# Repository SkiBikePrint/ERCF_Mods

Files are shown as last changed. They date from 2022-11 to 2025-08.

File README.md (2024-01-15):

# ERCF_Mods
These files are for a 2020 extrusion based ERCF top mounting that integrates into a set of handles for a Voron Trident or V2.  It includes a roller based spool feed system as well as a 3 and 4 slot 1000mm buffer design.
#
#





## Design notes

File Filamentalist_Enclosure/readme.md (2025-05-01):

# <h1 align="center"> The Filamentalist Enclosure repo can now be found as part of the ERCF V2 project as a User Mod [here](https://github.com/Enraged-Rabbit-Community/ERCF_v2/tree/master/Recommended_Options/Filamentalist_Rewinder/Filamentalist_Enclosure) <p align="center"> #

The Filamentalist Enclosure is a passive dry box designed to house the Filamentalist passive rewinder.  It  consists of (4) printed endcaps, (6) pieces of 2020 extrusion cut/ordered to the desired length, and 0.060" (1/16') polycarbonate sheet(s) cut to size. 

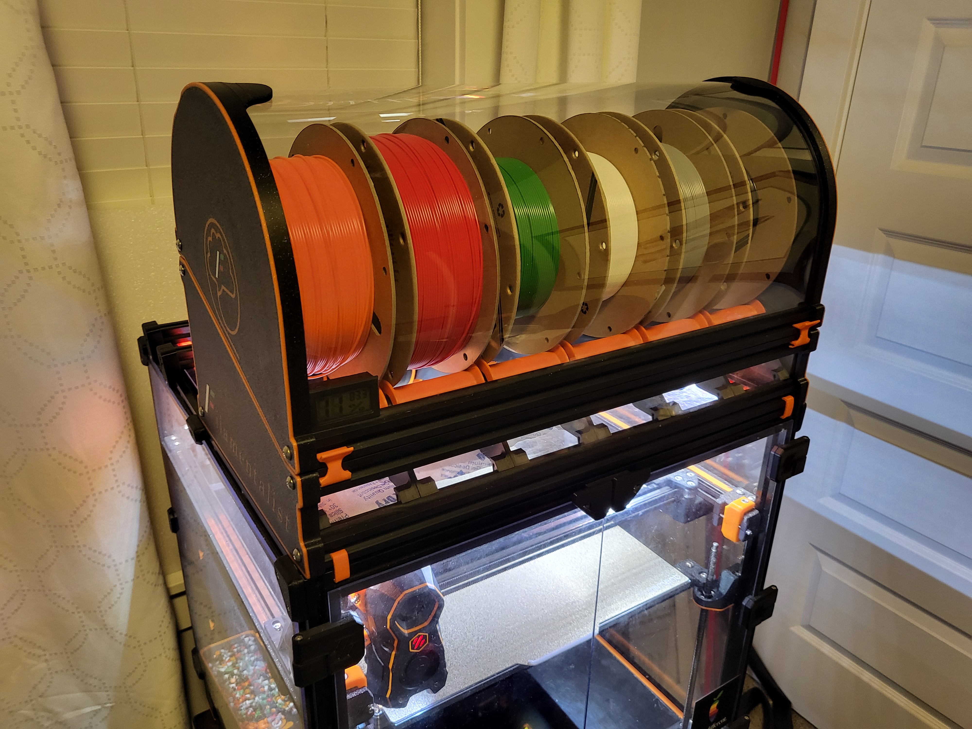
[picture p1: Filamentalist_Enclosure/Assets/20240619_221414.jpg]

</p>


</p>


</p>

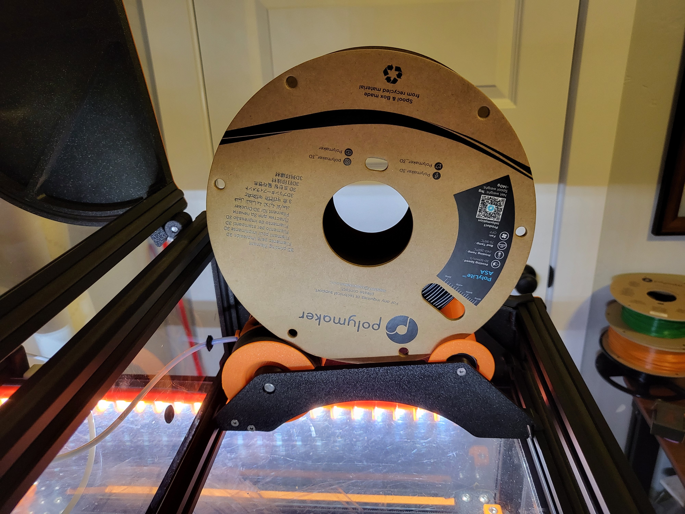
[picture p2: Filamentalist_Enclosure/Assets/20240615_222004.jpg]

</p>

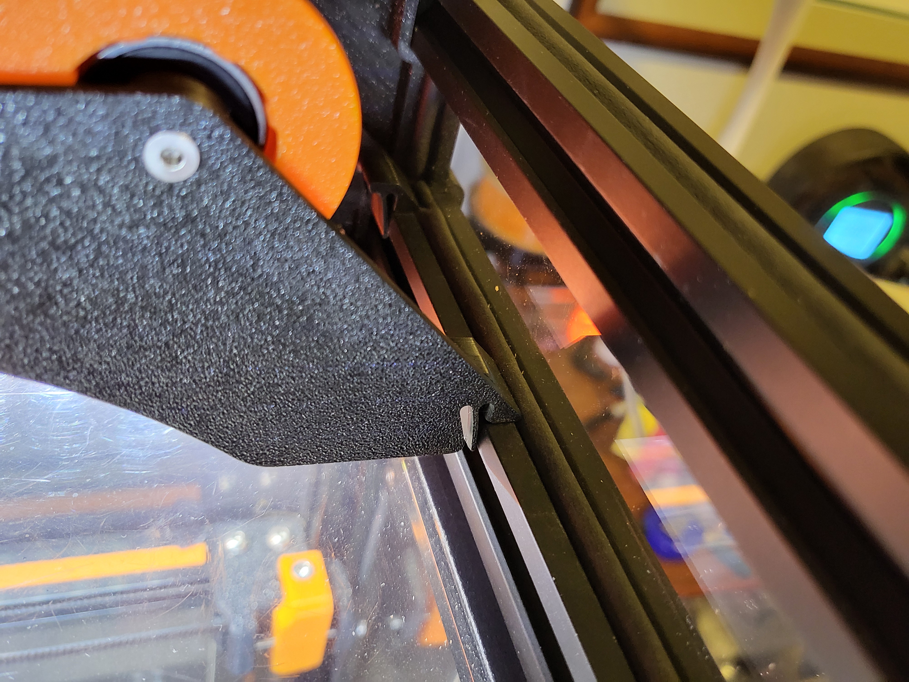
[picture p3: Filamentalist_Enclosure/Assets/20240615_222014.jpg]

</p>

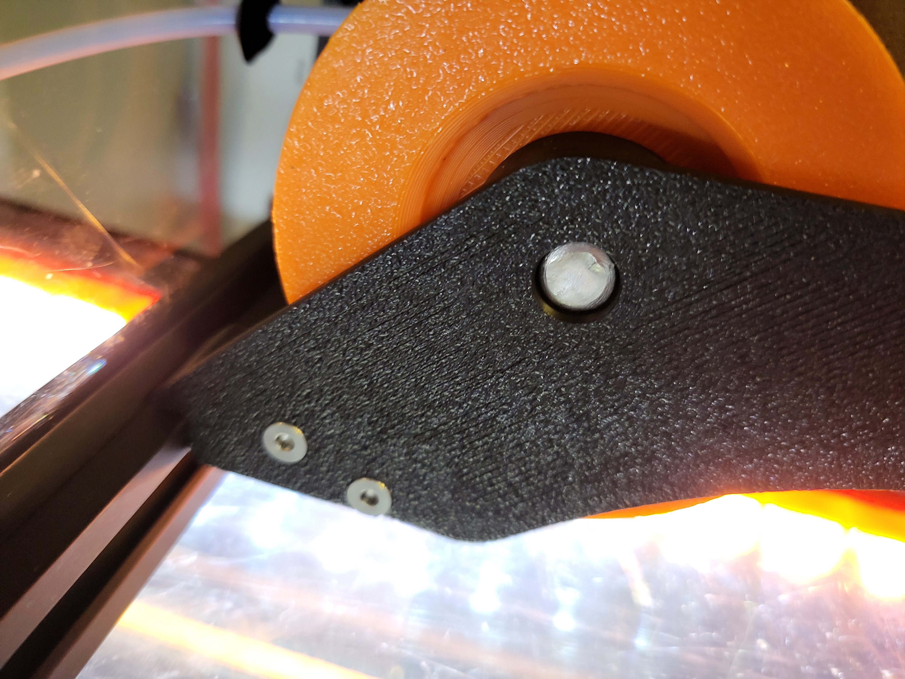
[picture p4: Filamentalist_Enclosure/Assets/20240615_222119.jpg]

</p>

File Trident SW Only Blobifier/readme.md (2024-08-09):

This allows for purging with blobs and using the hot end silicone jacket to knock the blobs off into a bin.  This is a solution for using Blobifier on a Trident.

I am loading/unloading my ERCF at 400/500 speed/accel (so pretty fast).  To be successful with that I want a pretty straight bowden run and this is why I chose to locate my Filametrix and purge site up front.  You can print multi-color up to ~35mm high under the gantry/toolhead, parts taller than this sacrifices the first ~100mm of build area at the font of the plate.  If you place yours in the rear you don't give up build space.  You will be limited to a max height of around 150mm. Taller than this and the part will hit the top of the enclosure when the plate returns to Z0 for blob formation.

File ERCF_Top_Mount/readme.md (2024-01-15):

This is a This is 2020 extrusion based top mount for the ERCF (Enraged Rabbit Carrot Feeder Multi-material unit developed by ette and the Voron community) 
on Voron 2.x and Trident printers.  The solution includes standalone end mounts adapted from NikosSprocket 
(https://www.printables.com/model/301808-ercf-frame-legs-for-voron-24-300mm) and 2020 mounts integrated into the "Sturdy Handle" adapted from synthden. 

Assembly tip:  The handles are designed to roll into the 2020 extrusion slots.  Because of this roll-in design, following the installation of the first 
handle the extrusions must be inserted to the full depth of the extrusion pockets to create enough space to roll in the opposing handle.  Once the second 
handle is installed, the extrusions can be partially slid back out from the first handle pockets and into the second handle pockets.  Now the extrusions are 
fully captured and can not come out without the removal of one (or both) handles.



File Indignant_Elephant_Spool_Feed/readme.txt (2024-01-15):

Indignant Elephant 2020 extrusion based simple spool roller

BOM

608-2RS Bearing qty (1)
M3x12 SHCS Screw (2)

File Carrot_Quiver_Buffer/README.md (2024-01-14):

# ERCF_Mods
The "Carrot Quiver" ( https://discord.com/channels/460117602945990666/909743915475816458/1040665326410530836 ) , and integrated multi-slot filament buffer to mount on the back of a 3D printer with a v-slot extrusion based frame or use with an intermediate frame system.

It allows a single 'loop' of filament to be buffered in the +/-1000mm range depending on printer frame height.  This system is intended to minimize filament path  drag compared to multi-loop wheel buffers and provide a quick and easy process for changing out filament spools.

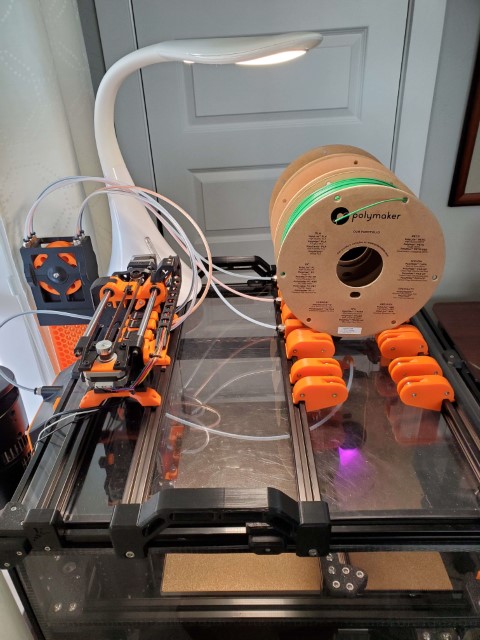
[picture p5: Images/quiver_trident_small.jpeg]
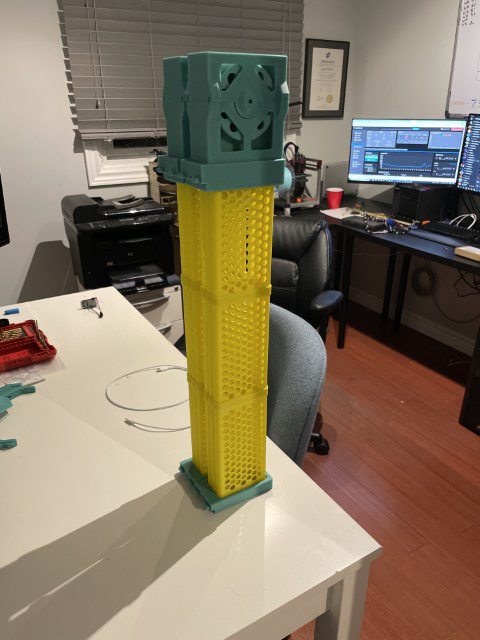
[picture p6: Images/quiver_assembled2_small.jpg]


## **BOM per 3 or 4 Slot Buffer:**

| **3/4 Slot Qty** | **Part** |
|---|---|
| 2/2 | 608-2RS bearing |
| 2/2 | M3x8 Socket Head Cap Screws (SHCS) to secure wheel axle (x12 or x16 length is fine too) |
| 6/8 | ECAS press-in pneumatic fittings for the bowden tubes (like used in ERCF) |
| 2/2 | M5 roll-in t-nuts for Top and Bottom frame mounts |
| 2/2 | M5x16 Socket Head Cap Screws for Top and Bottom frame mounts |
| 12/12 | 6x3mm neodymium magnets |

## **Printing Guidelines:**

## **General:**
- Material: ABS (~450 gm for 3 slot buffer and 600gm for 4 slot buffer)
- 0.2mm layer height
- 40% infill recommended (20% would be fine if you were in a hurry).  Linear style infills are fastest (rectilinear, monotonic, grid, triangles, stars, etc.)
- Wall Count: 4
- Solid Top/Bottom Layers: 5

## **Part Specific:**
- Orientation suggestions are relative to the installed part orientation in a vertically mounted quiver

## **Common for Trident and V2 all Z heights**

| **Qty** | **Part (3/4 3-slot/4-slot versions)** | **Orientation** | **Printed Supports Needed** |
|---|---|---|---|
| 1 | Axle | Vertical | N |
| 1 | Axle Spacer | Vertical | N |
| 1 | Bottom Block | Upside down | Y - under mounting overhangs |
| 1 | Filament Slots(3/4) Lower | Vertical | Y - under slot dividers at base |
| 1 | Top Mount | Vertical | Y - under slot dividers at base |
| 1 | Wheel | Horizontal | N |
| | -Slower printing 4-slot Spoke and Sexy Turbine options included | | |
| 1 | Wheel Block | Upside Down | N |

Wheel.stl, Axle.stl, Axle Spacer.stl

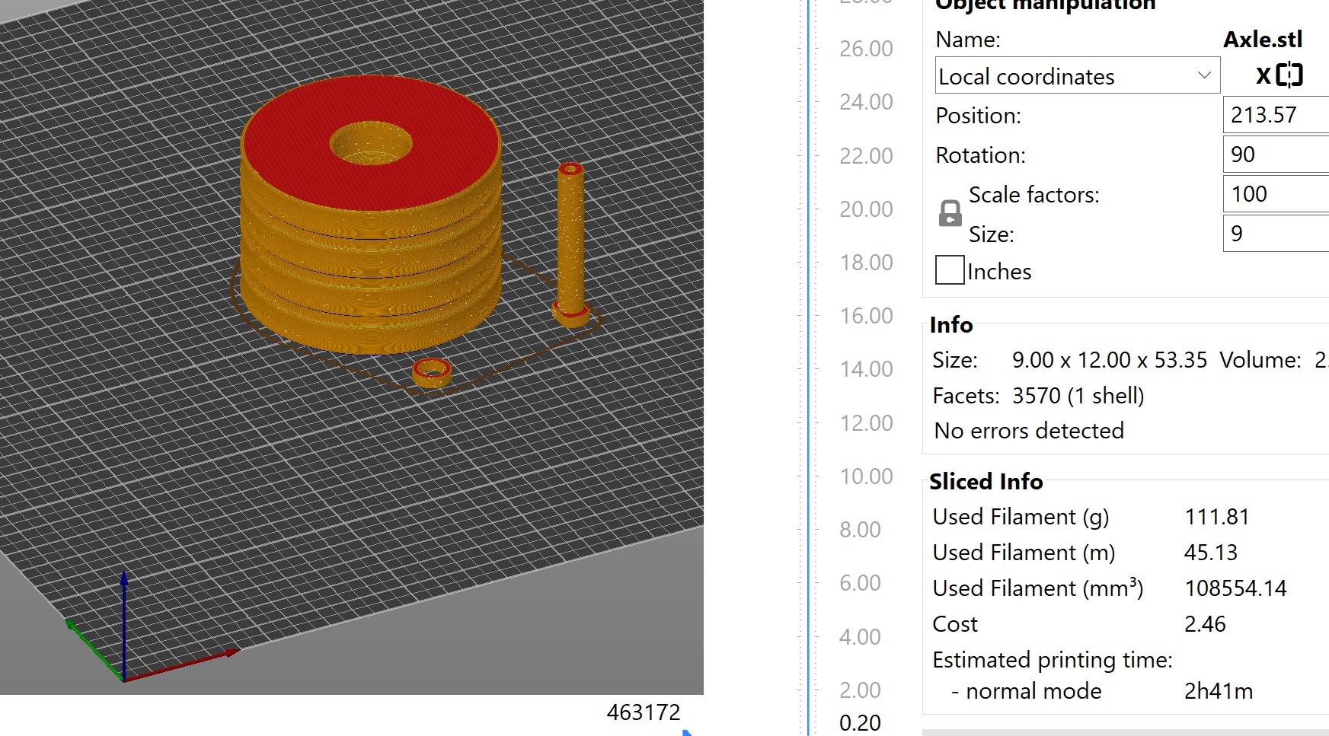
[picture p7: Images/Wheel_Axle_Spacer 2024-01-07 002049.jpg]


Bottom Block.stl



Filament Slots(3/4) Lower.stl



Top Mount.stl



Wheel Block.stl



>### Voron V2 Specific

| **Qty** | **Part** | Orientation |  **Printed Supports Needed** |
|---|---|---|---|
| 2 | Filament Slots(3/4) V2-(350/300/250) x2  | Vertical | Y - under slot dividers at base |

>### Voron Trident Specific (250mm Z travel)

| **Qty** | **Part** | Orientation |  **Printed Supports Needed** |
|---|---|---|---|
| 2 | Filament Slots(3/4) Trident x2 | Vertical | Y - under slot dividers at base |

Filament Slots(3/4) [...].stl



Assembly Steps:
1. Press fit the (2) MR608-2RS bearings into each side of the wheel. It is IMPORTANT to press to the full depth of the pocket in the wheel.  You can use a second wheel bearing as a pressing tool to drive the bearing in to full depth.
2. Press Axle through bearing flush to the shoulder on the axle.  
3. Press a total of (12) 6x3mm neodymium into the Wheel Block and Top Mount.  Take care to get orientation the same for all 6 on each part correct so that they attract to each other and allow for the Wheel Block to be oriented on the Top Mount in either direction as it is a symmetrical part.  Removal slots are designed in for the magnets if you need to pop any out.  These should be a strong press fit bit depending on your print toleraces you can add a dab of superglue in the bottom of each hole as you are installing (again, confirm orientation before commiting to glue!).  Also, note that the magnets that are located on the ends of the Wheel Block and Top Mount serve as alignment features.  The two on the top mount should slightly protrude above the surface (~1mm) and be recessed in the Wheel Block.  If further positive alignment is needed (but there shouldn't be a need) there is also holes in the these two parts for (2) M3 socket head cap screws.  You can screw the cap screws into the undersized holes in the Wheel Block.  The Top Mount has holes to receive the larger diameter of the socket head of the screws as a slip fit.
4. Press Axle Spacer onto axle flush to bearing.
5. Slide wheel and axle into Whell Block.  The is a keying feature in the wheel block to align to the flat edges on the shoulder feature of the axle.  This prevents the axle from spinning when installing/deinstalling the M3 axle screws.
6. Screw in M3x16 into holes in axles. You will be cutting threads in the axle plastic so do not over tighten.
7. This design is intentionally tight toleranced so that filament can not cross paths in the wheel tracks.  If there is any rubbing/interference with the wheel and Wheel Block or Top Mount, locate offending spot(s) and clean up with exacto, sandpaper, etc.
8. Mount top and bottom mounts onto printer extrusions in the desired location using M5 roll-in T-nuts and M5x16 socket head cap screws.  Once buffer is fully assembled it is necessary to remove the slots to access these screws so you will want to get the mounts positioned into their final location if possible.  It is not the end of the world if you have to move them, it just takes a few minutes to pop the slots back out of the mounts.
9. Slide the first section of the "Filament Slots 165" part into top mount.  It will not snap into place so you need to hold it in place for now (or temporaily tape it up).
10. Slide the second "Filament Slots 165" part into the slots above it.
11. Slide the third section, the "Filament Slots Lower 165" part (it has a floor) into the bottom mount from below.  Firmly press it upwards until it snaps into place.  If you need to remove this part to remove or relocate the buffer you can use a flat bladed screwdriver to gently pry each side of the buffer slots from below while pushing down on the buffer slots to clear the retention tabs.

Congratulations, you are ready load some carrots into your quiver!  Does that sound inappropriate...???

I will caution that this design has tight tolerances around the wheel so that filament can not get lodged in any gaps or neighboring slots.  This means the axle needs to be aligned well and any rubbing between the wheel and the upper quiver parts may need to be filed, sanded, exacto knifed away.  I use 3 mm and 4mm drill bits to clean up the bowden tube holes.  ~41mm of 4mm bowden tubing should insert through the fitting and down to where it seats in the Wheel Block.  If it does not go in ~41mm then the hole needs to be cleaned out with a 4mm drill bit.  Do not clean out the hole any deeper than 41mm as there is a step down to 3.2mm at this point to serve as a stop for the tubing.  You can run a 3mm drill bit through the entire hole if necessary to ensure an open path for filament.  So this design does require a little bit of post processing and tuning but once right it works well and is easy to thread and gain access to the filament.  All these little measures result in a surprisingly easy buffer to load.

Happy multi-color printing!
#





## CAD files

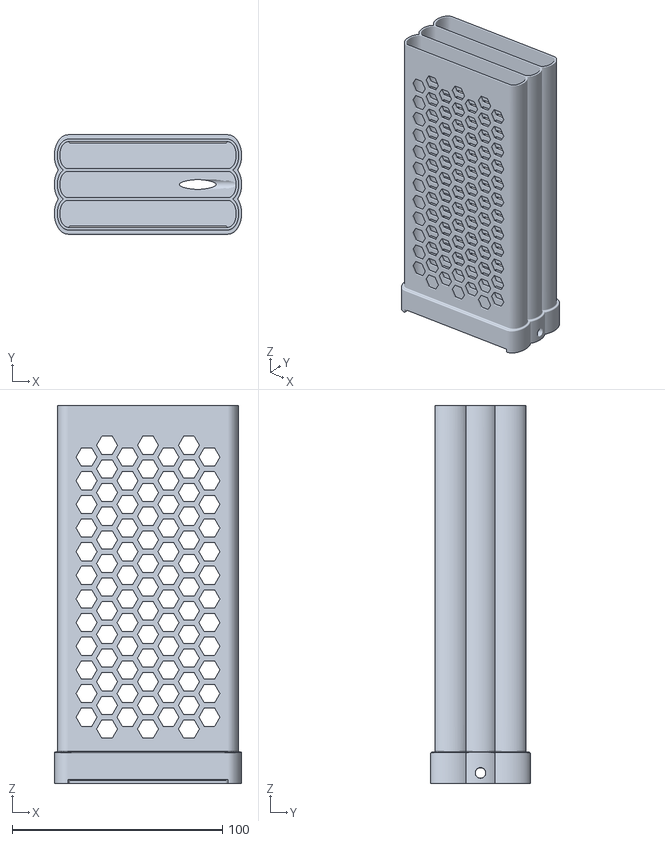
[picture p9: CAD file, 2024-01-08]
Carrot_Quiver_Buffer/3 Slot/Filament Slots(3) Lower.stl
89.2 x 47.4 x 180.0

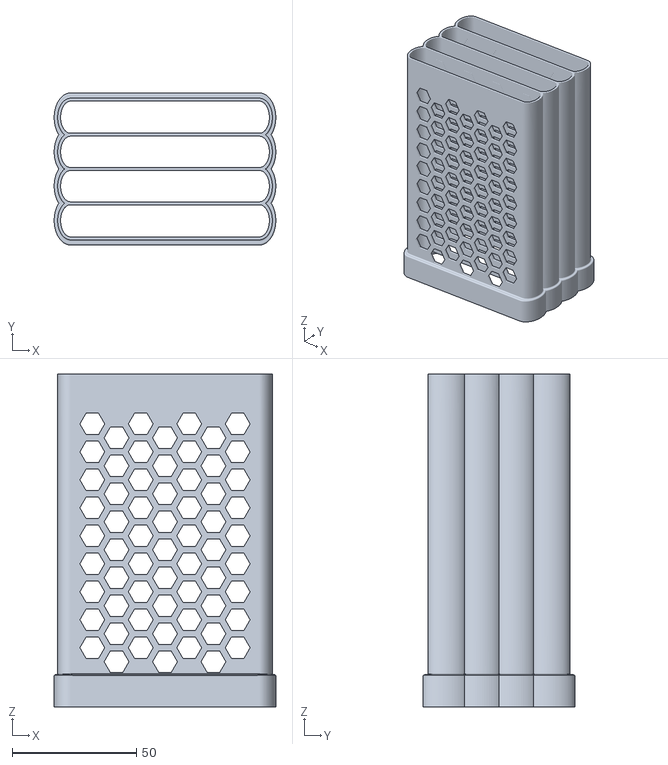
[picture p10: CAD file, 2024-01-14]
Carrot_Quiver_Buffer/4 SLot/Filament Slots(4) V2-250 x2.stl
89.2 x 61.2 x 134.0

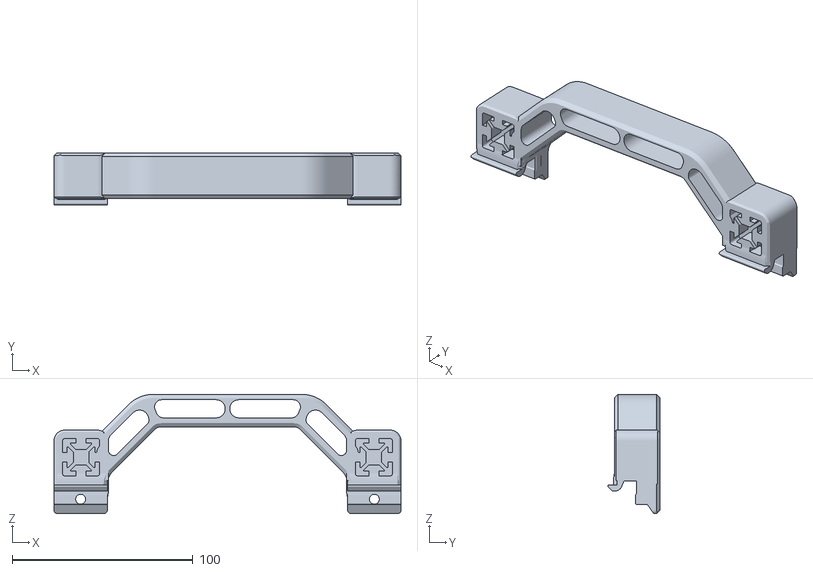
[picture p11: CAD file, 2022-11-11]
ERCF_Top_Mount/ERCF Sturdy Handle Frame Mount v3.stl
191.8 x 28.9 x 66.0

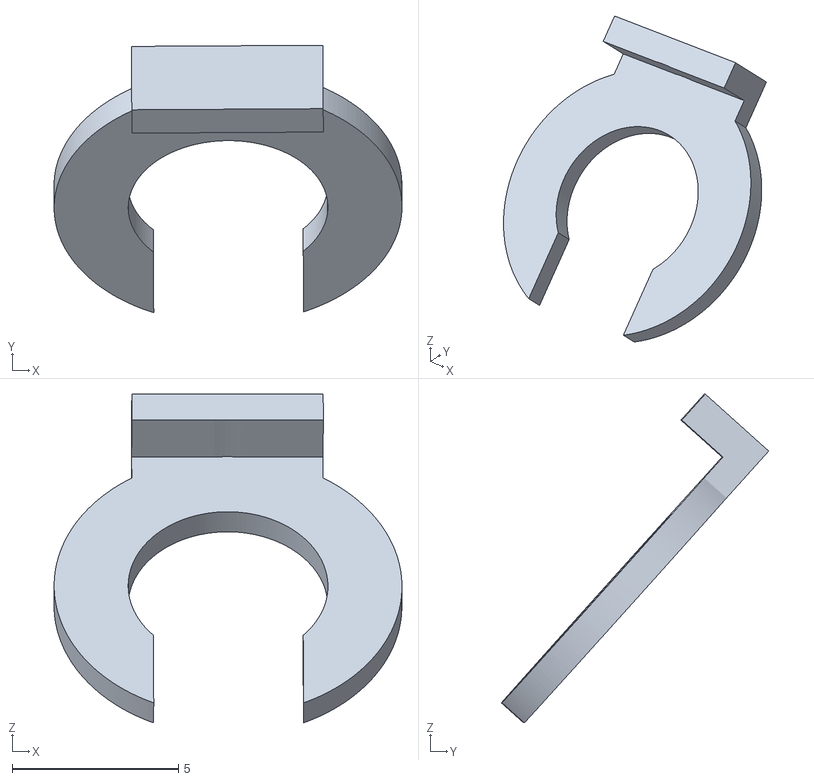
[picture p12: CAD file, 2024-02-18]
Filamentalist/STL's/ECAS Clip v21.stl
10.5 x 8.03 x 9.88

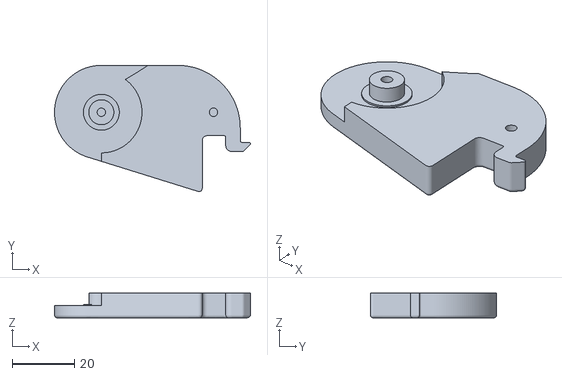
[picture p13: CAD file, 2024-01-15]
Indignant_Elephant_Spool_Feed/Bearing Clip Right.stl
62.7 x 40.4 x 8.00

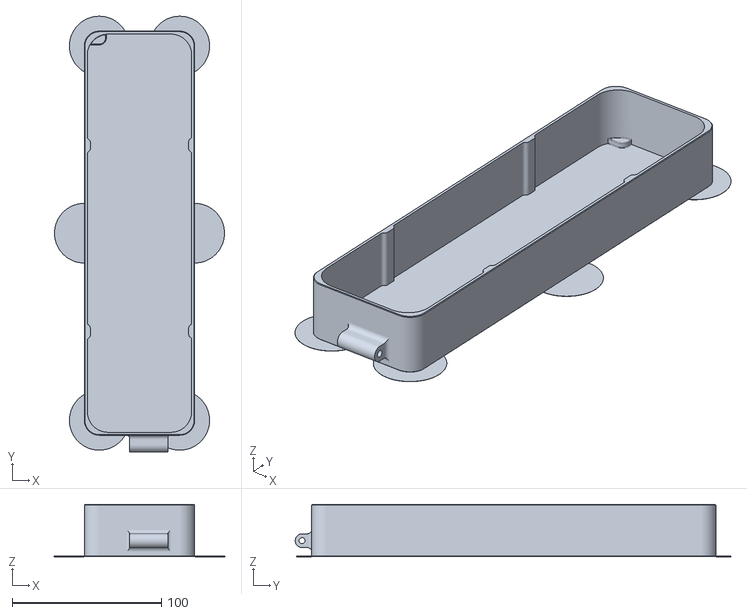
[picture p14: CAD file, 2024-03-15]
Trident SW Only Blobifier/stls/Blob Bucket 250.stl
114.0 x 292.1 x 35.0

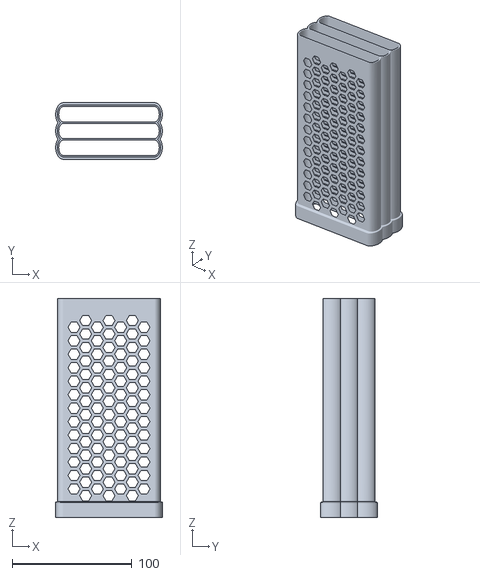
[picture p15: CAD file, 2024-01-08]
Carrot_Quiver_Buffer/3 Slot/Filament Slots(3) V2-350 x2.stl
89.2 x 47.4 x 183.0

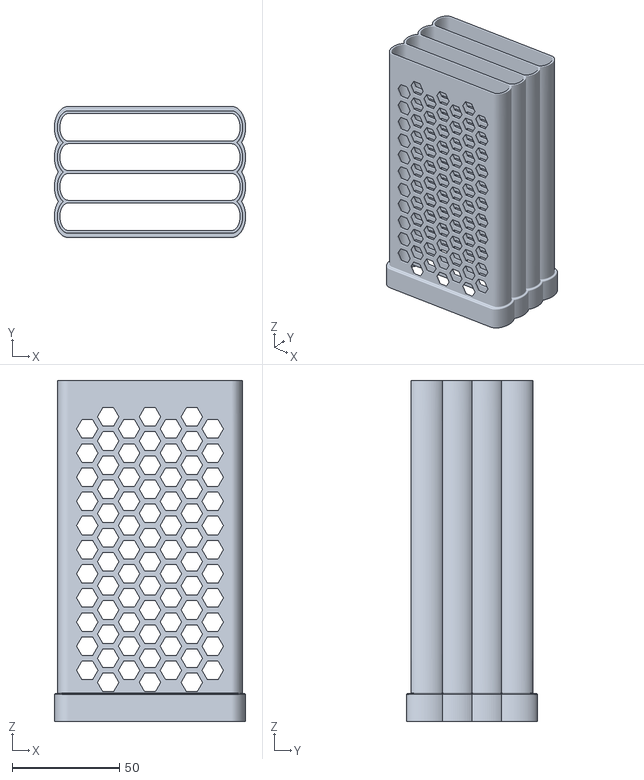
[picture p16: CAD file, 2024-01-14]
Carrot_Quiver_Buffer/4 SLot/Filament Slots(4) V2-300 x2.stl
89.2 x 61.2 x 159.0

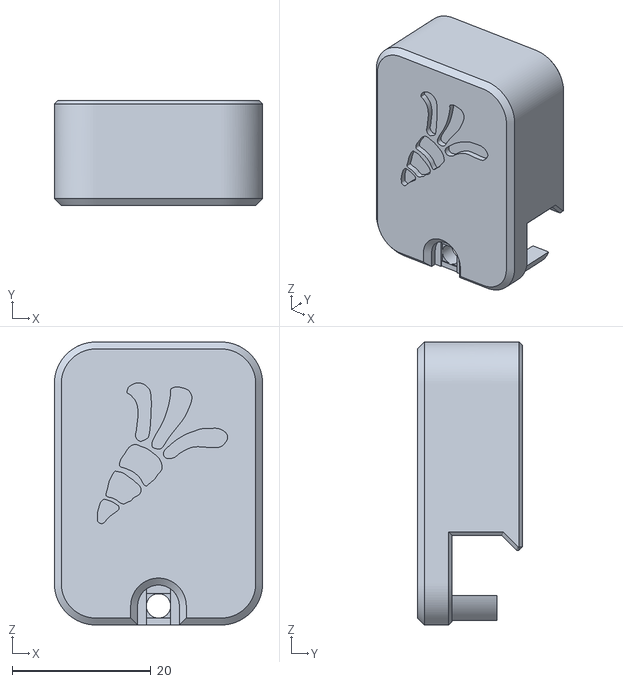
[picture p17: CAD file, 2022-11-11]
ERCF_Top_Mount/ERCF Frame Mount v3.stl
30.0 x 15.1 x 40.8

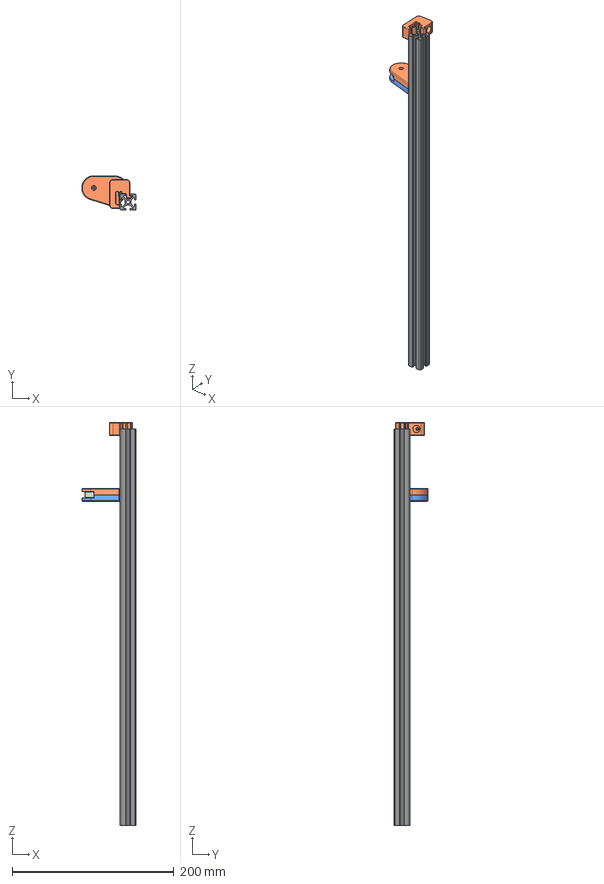
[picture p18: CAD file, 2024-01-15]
Indignant_Elephant_Spool_Feed/2020 Mounted Spool Rollers v1.step
67.3 x 42.5 x 498.0 mm
5537T751_T-Slotted Framing
Bearing Clip Left
Bearing Clip Right
Bowden Mount
2349K744_Permanently Lubricated Ball Bearing (5) (2) (1)

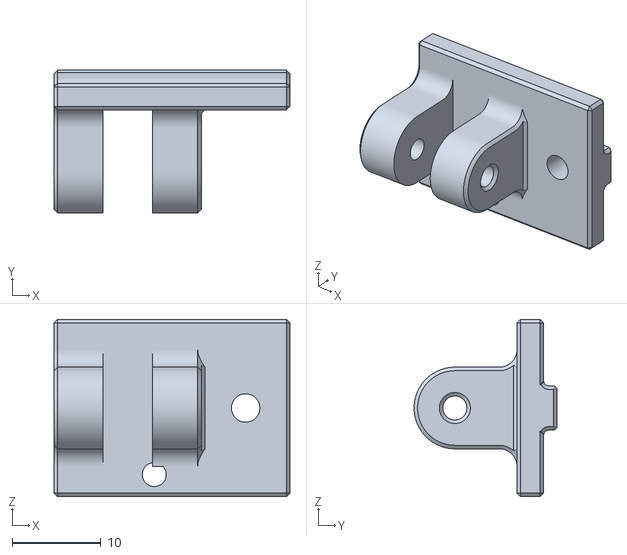
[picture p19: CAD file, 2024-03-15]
Trident SW Only Blobifier/stls/Arm Mount.stl
26.6 x 16.1 x 20.0

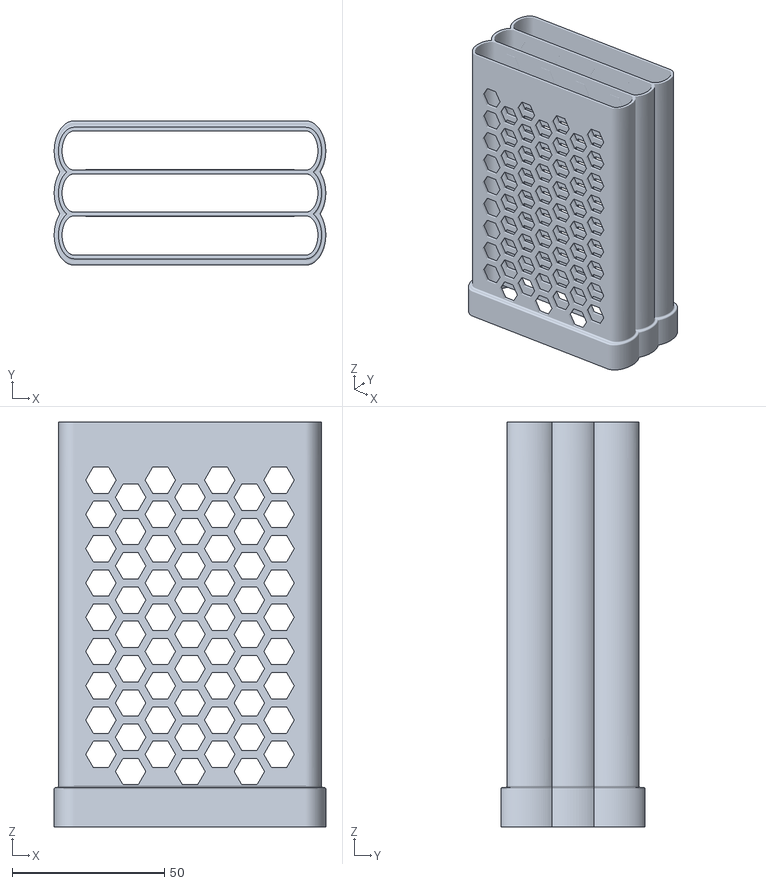
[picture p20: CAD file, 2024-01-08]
Carrot_Quiver_Buffer/3 Slot/Filament Slots(3) V2-250 x2.stl
89.2 x 47.4 x 133.0

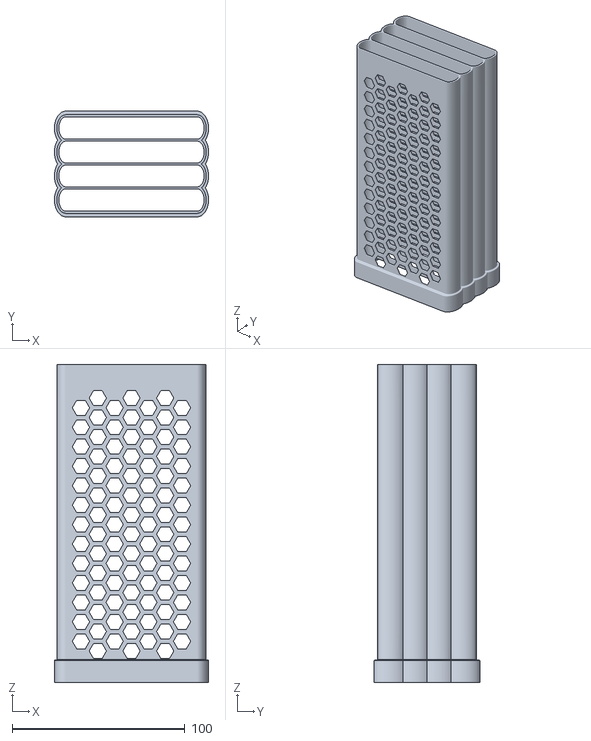
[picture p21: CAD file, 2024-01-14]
Carrot_Quiver_Buffer/4 SLot/Filament Slots(4) V2-350 x2.stl
89.2 x 61.2 x 184.0

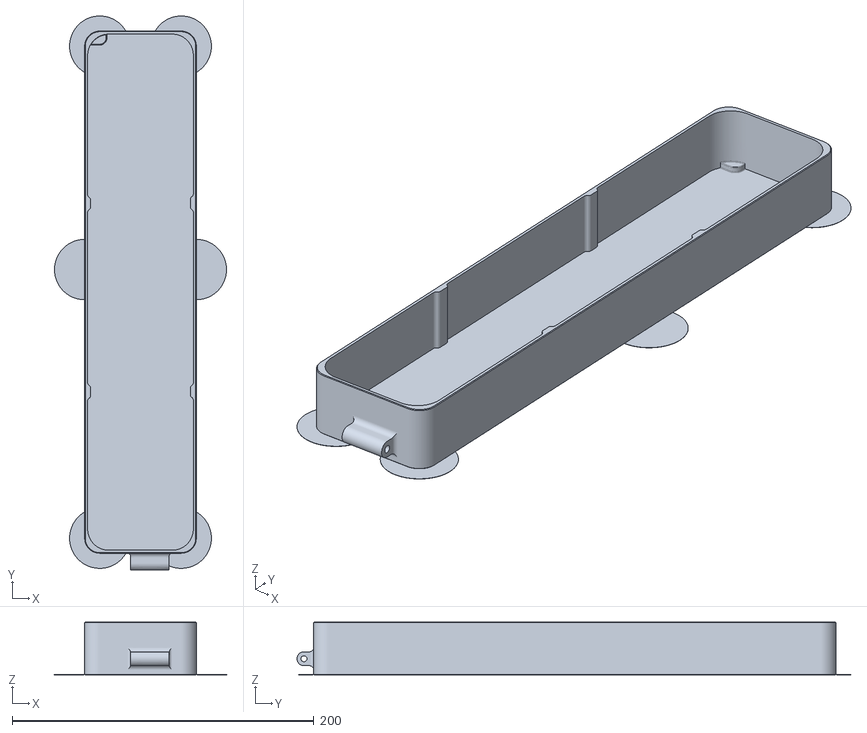
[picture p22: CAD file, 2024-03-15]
Trident SW Only Blobifier/stls/Blob Bucket 350.stl
114.0 x 367.1 x 35.0

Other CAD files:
Indignant_Elephant_Spool_Feed/Bearing Clip Left.stl
Carrot_Quiver_Buffer/3 Slot/Filament Slots(3) V2-300 x2.stl
Carrot_Quiver_Buffer/4 SLot/Filament Slots(4) Lower.stl
Indignant_Elephant_Spool_Feed/Bowden Mount.stl
Carrot_Quiver_Buffer/3 Slot/Axle Spacer.stl
Carrot_Quiver_Buffer/3 Slot/Axle.stl
Carrot_Quiver_Buffer/3 Slot/Bottom Block.stl
Carrot_Quiver_Buffer/3 Slot/Filament Slots(3) Trident x2.stl
Carrot_Quiver_Buffer/3 Slot/Top Mount.stl
Carrot_Quiver_Buffer/3 Slot/Wheel Block.stl
Carrot_Quiver_Buffer/4 SLot/Axle.stl
Carrot_Quiver_Buffer/4 SLot/Bottom Block.stl
Carrot_Quiver_Buffer/4 SLot/Filament Slots(4) x2 Trident.stl
Carrot_Quiver_Buffer/4 SLot/Top Mount.stl
Carrot_Quiver_Buffer/4 SLot/Wheel Block.stl
Indignant_Elephant_Spool_Feed/2020 Mounted Spool Rollers v0.f3d
Trident SW Only Blobifier/stls/Arm Lower.stl
Trident SW Only Blobifier/stls/Arm Upper.stl
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

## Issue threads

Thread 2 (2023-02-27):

The wheel block geometry is badly broken

jwhite, 2023-02-27:
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

As you can see, there are numerous bad polygons and shifted faces on the inside of both models.

jwhite, 2023-03-18:
I fixed this in the pull request https://github.com/SkiBikePrint/ERCF_Mods/pull/4

SkiBikePrint, 2024-01-13:
I incorporated your cleaned up geometry.  Thanks!

Closed 2024-01-13.

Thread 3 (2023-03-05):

Need a way to get Top Handle Extrusion Mount onto the printer

pfielding, 2023-03-05:
The top handle extrusion mount looks great, but I don't see any way to actually mount it on the printer without taking apart the extrusion on the printer.  The handle needs to normally tilt inwards to be able to clip into the printer extrusion, but the top extrusion that it will be holding, prevents the handle from tilting.  Any suggestion on how to actually mount the thing would be awesome....

jwhite, 2023-03-18:
The quiver slots up from the bottom, through the bottom mount, and then up into the top mount.

You don't mount the top mount with the qwiver parts (the mesh) inside.

The instructions were good, but a bit hard to follow.

SkiBikePrint, 2024-01-15:
I created a readme with these instructions I had posted on Thingiverse when I originally created this design: "Assembly tip: The handles are designed to roll into the 2020 extrusion slots. Because of this roll-in design, following the installation of the first handle the extrusions must be inserted to the full depth of the extrusion pockets to create enough space to roll in the opposing handle. Once the second handle is installed the extrusions can be then be slid back out from the first handle pocket and into the second handle pockets. Now the extrusions are fully captured and can not come out without the removal of one (or both) handles."

Closed 2024-01-15.

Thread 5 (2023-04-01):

PC4-M10 ptfe ports.. and tolerances?

LAP87, 2023-04-01:
So i've printed and reprinted the M3 wheel block with the holes for the ptfe connectors, but each time they crack and/or bulge the plastic around the hole and end up crooked.
Could you please fix the hole geometries so they can print supportless  (like voron parts), and also add M10 threads + tolerances?

M3 bolt holes are way too small for easy heat set insert insertion.

Also, i don't think you mention anywhere the preferred orientation for printing any of the parts.

LAP87, 2023-04-01:
Or add an optional ECAS04 port version of the top, i have a bag full of those!

SkiBikePrint, 2024-01-13:
The design is now ECAS only.

Closed 2024-01-13.

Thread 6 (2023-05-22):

Missing hole in Top/Bottom Mount?

Surion79, 2023-05-22:
I am currently trying to attach the Quiver to my printer, but while the BOM states the 2x M5x16 SHCS for mounting the Quiver, I don't see a chance to mount the Top Mount with the M5x16. The Upper Quiver stls have a hole which are apparently used for accessing the screw, but on the Top Mount, the opposite hole to access the M5x16 screw is missing.

The manual is exactly missing that bit of info how to tighten/access the M5x16 screw of the Top Mount.
Is there a hole missing in Top Mount? You can't access any M5x16 screws when the Quiver is fully assembled, which is required to attach it to the printer on both ends.

SkiBikePrint, 2024-01-13:
The mounts are installed prior to installing the slots which provides access to the M5 screws.

Closed 2024-01-13.

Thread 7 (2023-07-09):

Indignant_Elephant_Spool_Feed should have "washers" built in for the bearings!

grmocg, 2023-07-09:
The 608s I have are loose in the elephant, and rub along the sides when rolling.
If a small "washer" was put into the model around the bearing spindle, that'd be prevented, and the rollers would always roll as smoothly as they could!

SkiBikePrint, 2024-01-15:
Stand-off "washers" have been added.

Closed 2024-01-15.

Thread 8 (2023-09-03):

M5 heat insert, please mention outside Diameter?

MaikelKelder, 2023-09-03:
I printed the M5 heat insert version, but the M5 heat inserts I have are WAY too small and too long for this hole.

Please specify diameter of the used M5 heat insert, since its far from default.

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

MaikelKelder, 2023-09-03:
The hole is 8.9mm and 7.15mm deep.
For the next one, I now need to find and order right inserts..

SkiBikePrint, 2024-01-13:
M5 version has been removed

Closed 2024-01-13.

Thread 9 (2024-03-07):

Gear stepper gearing, NEMA17, etc..

moggieuk, 2024-03-07:
"Potential for being on the edge of gear motor stall. We are close to the stall threshold so the risk is that there is enough variation in the user community's ERCF builds, motors, and buffer builds that stall arises as an issue. I definitely have occasionally experienced stall if something caused a small increase in resistance. I may need to go NEMA17 to provide the headroom but will test on NEMA14 first."

Using an issue to provide some thoughts on this.  We know that the gearing for the gear stepper on the ERCF design is WAY off the optimum speed/torque point.   Obviously a NEMA17 is one way to go but better gearing is going to help.  This is something we have been experimenting with in a reworked gearbox design for a future ERCF update...  JFYI

thisiscam, 2024-03-11:
I believe a few testers are using the 1:2 gear mod by grafton (who is also testing the rewinder), and that worked well.
https://www.printables.com/model/692720-ercf-40-tooth-gear-modifiction.

For tradrack stock gear motor, the torque and gear ratio is plenty!

SkiBikePrint, 2024-03-16:
I am running Grafton's 40 tooth mod on the V2 and a NEMA 17 rated at 55Ncm torque and 2.0A holding current.  I have the max current configured at 1.2A and only see stalling when you would want it :)

Closed 2024-03-16.

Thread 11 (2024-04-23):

How to utilize pre_gate sensor in ERCF v2 with Quiver buffer?

AlexTOOT, 2024-04-23:
Thanks for the great work, I really enjoy the quiver buffer, simple but elegant design.

I'm wondering how to use pre-gate sensors together with it, I'm currently having cotton tail and quiver installed at the same time, filament goes through quiver to ERCT pre-gate sensor, pretty nasty. Is there a mod you recommend or a plan to introduce pre-gate sensors into quiver?

AlexTOOT, 2024-05-02:
To whom this might concern.
I found this triple-decky C9 version.
https://github.com/gneu42/Triple-Decky/tree/main

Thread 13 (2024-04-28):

Wrong O-ring size called up

1scottlyl, 2024-04-28:
The BOM states a 110 O-ring, where the amazon link is to a 211 O-ring. A 110 O-ring will not fit around the center roller.

Closed 2024-04-28.

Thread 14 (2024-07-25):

Filamentalist_Enclosure for Voron 2.4

salbang, 2024-07-25:
What would be the good extrusion length for voron 2.4 to have a nice fit on top of the printer?

Could you please explain some relative size like
voron 2.4 width +/- xxmm?

Thank you.

salbang, 2024-08-01:
Based on my measurement on the right and left endcap lid thickness, which is 10mm each, it seems that the right size for the extrusion length is voron 2.4 width - 20mm.

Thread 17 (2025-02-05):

Broken link to ERCF

bsafh, 2025-02-05:
This link https://github.com/Enraged-Rabbit-Community/ERCF_v2/tree/master/Recommended_Options/Filamentalist_Rewinder/User_Mods/SkiBikeMake/Filamentalist_Enclosure is broken,  so .. where are the STLs?

jusii, 2025-02-13:
Guess it's here https://github.com/Enraged-Rabbit-Community/ERCF_v2/tree/master/Recommended_Options/Filamentalist_Rewinder/User_Mods/Filamentalist_Enclosure

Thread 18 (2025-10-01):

Filamentalist Enclosure for Filamentalist V3

carl1961, 2025-10-01:
looked every where, the mounts in cad for Enclosure look like in picture. But I cannot figure out what I am missing here. what is the part that make this work together. is the enclosure actually for a older version? might have to make custom mounts to use this Enclosure?

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

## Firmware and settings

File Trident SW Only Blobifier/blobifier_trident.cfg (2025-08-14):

##########################################################################################
# Main macro. Usually you should only need to call this one or place it in the Happy Hare
# _MMU_POST_LOAD macro or variable_user_post_load_extension:
# PURGE_LENGTH=[float] (optional) The length to purge. If ommited it will check the 
#                      purge_volumes matrix or variable_purge_length
#PURGE_RET=[float]    (optional) The length to retract between moves
#
[gcode_macro BLOBIFIER_TRIDENT]
# These parameters define your filament purging. The retract variable is used to retract 
# right after purging to prevent unnecessary oozing. Some filament are particularly oozy 
# and may continue to ooze out of the nozzle for a second or two after retracting. Update 
# as necessary.
variable_purge_spd: 400	     # 8/10/24 - default 400, trying 200 (8 mm3/s) for TPU - Speed, in mm/min, of the purge.
variable_purge_temp_min: 255	     # Minimum nozzle purge temperature.
variable_retract_before_park: 0.0     # gpw - was 1 - amount in mm. 0 to disable
variable_retract_speed: 2000       # mm/m

# Adjust this so that your nozzle scrubs within the brush. Be careful not to go too low! 
# Start out with a high value (like, 6) and go 
# down from there.
#variable_brush_top: 6 

# These parameters define your scrubbing, travel speeds, safe z clearance and how many 
# times you want to wipe. Update as necessary.
variable_clearance_z: 2	         # When traveling, but not cleaning, the 
                                           #   clearance along the z-axis between nozzle 
                                           #   and brush.
#variable_wipe_qty: 2	         # Number of complete (A complete wipe: left, 
                                           #   right, left OR right, left, right) wipes.
variable_travel_spd_xy: 10000	         # Travel (not cleaning) speed along x and 
                                           #   y-axis in mm/min.
variable_travel_spd_z: 1000	         # Travel (not cleaning) speed along z axis 
                                           #   in mm/min.
variable_wipe_spd_xy: 10000	         # Nozzle wipe speed in mm/min.


# These parameters define the size of the brush. Update as necessary. A visual reference 
# is provided below.
# 
#                  ?   brush_width   ?                            
#                   _________________                                                          
#                  |                 |  ?                Y position is acquired from your 
#  brush_start (x) |                 | brush_depth       stepper_y position_max. Adjust 
#                  |_________________|  ?                your brush physically in Y so 
#                          (y)                           that the nozzle scrubs within the 
#                      brush_front                       brush.                                              
# __________________________________________________________
#                     PRINTER FRONT
# 
# 
# Start location of the brush. Defaults for 250, 300 and 350mm are provided below. 
# Uncomment as necessary
#variable_brush_start:          34	# For 250mm build    
#variable_brush_start:           67  # For 300mm build
variable_brush_start:          3  # gpw - revised for my setup - for 350mm build

# width of the brush
#variable_brush_width:          35	

# Location of where to purge. The tray is 15mm in length, so if you assemble it against 
# the side of the bed (default), 10mm is a good location
variable_purge_x: 3

# Height of the tray. If it's below your bed, give this a negative number equal to the 
# difference. If it's above your bed, give it a positive number. You can find this number 
# by homing, optional QGL or equivalent, and moving you toolhead above the tray, and 
# lowering it with the paper method. 
variable_tray_top: 0.0


# ========================================================================================
# ==================== BLOB TUNING =======================================================
# ========================================================================================

# The following section defines how the purging sequence is executed. This is where you 
# tune the purging to create pretty blobs. Refer to the visual reference for a better 
# understanding. The visual is populated with example values. Below are some guides 
# provided to help with tuning.
#
#                          \_____________/
#                             |___|___|
#                                \_/            ______________  < End of third iteration.
#                                / \                                  HEIGHT:   3 x iteration_z_raise - (2 + 1) x iteration_z_change  (3 x 5 - 2 x 1.2 = 11.4)
#                               |   |                                 EXTRUDED: 3 x max_iteration_length                              (3 x 50 = 150)
#                              /     \          ______________  < End of second iteration.
#                             |       \                               HEIGHT:   2 x iteration_z_raise - 1 x iteration_z_change        (2 x 5 - 1 x 1.2 = 8.8)
#                            /         |                              EXTRUDED: 2 x max_iteration_length                              (2 x 50 = 100)
#                           |           \       ______________  < End of first iteration. 
#                          /             \                            HEIGHT:   1 x iteration_z_raise                                 (1 x 5 = 5)
#                         |               |                           EXTRUDED: 1 x max_iteration_length                              (1 x 50 = 50)
#___________               \             /      ______________  < Start height of the nozzle. default value: 1.5mm
#           |_______________\___________/_      ______________  < Bottom of the tray
#           |_____________________________|
#           |
# 
########################### BLOB TUNING ##############################
# +-------------------------------------+----------------------------+
# |  Filament sticks to the nozzle at   | Incr. purge start          |
# |    initial purge (first few mm)     |                            |
# +-------------------------------------+----------------------------+
# |  Filament scoots out from under     | Incr. temperature          |
# |  the nozzle at the first iteration  | Decr. z_raise              |
# |                                     | Incr. purge_length_maximum |
# +-------------------------------------+----------------------------+
# |  Filament scoots out from under the | Decr. purge_spd            |
# |  the nozzle at later iterations     | Decr. z_raise_exp          |
# |                                     | Decr. z_raise              |
# |                                     | Incr. purge_length_maximum |
# +-------------------------------------+----------------------------+
# |  Filament sticks to the nozzle at   | Incr. z_raise_exp          |
# |         later iterations            |     (Not above 1)          |
# +-------------------------------------+----------------------------+
#

# The height to raise the nozzle above the tray before purging. This allows any built up 
# pressure to escape before the purge.
variable_purge_start: 0.2  # gpw - was 0.2


# The amount to raise Z
variable_z_raise: 15   # gpw - Should it be 19.5? 6.5[iteration_z] X 3[max_iterations_per_blob] from old version - 16.8 default (was this calculated from my previous version's settings?)

# As the nozzle gets higher and the blob wider, the Z raise needs to be reduced, this
# follows the following formula: 
#            (extruded_amount/max_purge_length)^z_raise_exp * z_raise
# 1 is linear, below 1 will cause z to raise less quickly over time, above 1 will make it
# raise quicker over time. 0.85 is a good starting point and you should not have it above 1
variable_z_raise_exp: 0.9  # gpw - 0.85 default

# Lift the nozzle slightly after creating the blob te release pressure on the tray.
variable_eject_hop: 0.0  

# Dwell time (ms) after purging and before cleaning to relieve pressure from the nozzle.
variable_pressure_release_time: 0  #gpw - was 1000

# Set the part cooling fan speed. Disabling can help prevent the nozzle from cooling down 
# and stimulate flow, Enabling it can prevent blobs from sticking together. Values range 
# from 0 .. 1, or -1 if you don't want it changed.
#variable_part_cooling_fan: -1              # Leave it unchanged
#variable_part_cooling_fan:  0              # Disable the fan
variable_part_cooling_fan:  1               # Run it at full speed


# ========================================================================================
# ==================== PURGE LENGTH TUNING ===============================================
# ========================================================================================
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

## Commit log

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2022-11-25 Add files via upload
    1. Updated the 8mm magnet press-in holes to eliminate break-out.
    2. Added an M3 wheel axle version for those how don't have M5 heat sets (choose "Wheel Block M3 Heat Set.stl" and "Axle M3.stl"
    [Axle M3.stl, Top Mount.stl, Wheel Block M3 Heat Set.stl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]
2022-11-25 Delete Wheel Block.stl
    Replaced with new version that prevents breakout when magnets are pressed in.
    [Wheel Block.stl]
2022-11-27 Modified to a 2 bearing wheel to improve lateral stability.
    [Axle M3 2 Bearing.stl, Axle M5 2 Bearing.stl, Axle Spacer 2 Bearing.stl]
2022-11-27 Delete Axle M3.stl
    Converting to a 2 Bearing design.
    [Axle M3.stl]
2022-11-27 Delete Axle Spacer.stl
    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
    [Axle Spacer.stl]
2022-11-27 Delete Axle.stl
    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
    [Axle.stl]
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2022-11-30 Add files via upload
    Revised Bearing Clip Right.stl to use the standard heatset inserts that use a 4.7mm diameter hole.
    [Bearing Clip Right.stl]
2022-12-22 Delete Wheel-2 Bearing.stl
    Adding in a new version with clearance around the axle.
2022-12-22 Add files via upload
    Revised wheel to have a 14mm center bore for clearance around axle.
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2024-01-08 Add files via upload
    Closed unnecessary "air bridge" in Filament Slots(3) Lower.stl for the center dividers. Exterior faces should be unconnected and supports used while printing. This provides the spring clip-in flexibility for snapping into the Bottom Mount.
    [Filament Slots(3) Lower.stl]
2024-01-08 Add files via upload
    Closed unnecessary "air bridge" in Filament Slots(4) Lower for the center dividers. Exterior walls should be unconnected at the base and supports used while printing. This provides the spring clip-in flexibility for snapping into the Bottom Mount.
    [Filament Slots(4) Lower.stl]
2024-01-13 Delete Carrot_Quiver_Buffer/Axle M3 2 Bearing.stl
    Removing old files based on the 1/7/24 update that added a 4-slot version and V2 support for 250/300/350 printers.
    [Axle M3 2 Bearing.stl]
2024-01-13 Delete Carrot_Quiver_Buffer/Axle M5 2 Bearing.stl
    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
    [Axle M5 2 Bearing.stl]
2024-01-13 Delete Carrot_Quiver_Buffer/Axle Spacer 2 Bearing.stl
    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
    [Axle Spacer 2 Bearing.stl]
2024-01-13 Delete Carrot_Quiver_Buffer/Bottom Block.stl
    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
    [Bottom Block.stl]
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2024-01-13 Delete Carrot_Quiver_Buffer/Filament Slots Lower.stl
    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
    [Filament Slots Lower.stl]
2024-01-13 Delete Carrot_Quiver_Buffer/Filament Slots Upper.stl
    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
    [Filament Slots Upper.stl]
2024-01-13 Delete Carrot_Quiver_Buffer/Top Mount.stl
    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
    [Top Mount.stl]
2024-01-13 Delete Carrot_Quiver_Buffer/Wheel Block M3 Heat Set.stl
    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
    [Wheel Block M3 Heat Set.stl]
2024-01-13 Delete Carrot_Quiver_Buffer/Wheel Block M5 Heat Set.stl
    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
    [Wheel Block M5 Heat Set.stl]
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2024-01-14 Add files via upload
    Added 1mm in height to V2 Filament Slots to eliminate the 2mm clearance on the original design. There was feed back that there was too much play in the slot-to-slot sleeving.
    [Filament Slots(4) V2-250 x2.stl, Filament Slots(4) V2-300 x2.stl, Filament Slots(4) V2-350 x2.stl]
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2024-01-15 Add files via upload
    Revised bearing clip for threading into plastic vs using heatset inserts. Added CAD files.
    [2020 Mounted Spool Rollers v0.f3d, 2020 Mounted Spool Rollers v1.step, Bearing Clip Left.stl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]
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2024-01-26 Delete Filamentalist/Filament Drive Buffer V4 v66.f3d
    Adding revised files to address Tensioner Mnt mounting error.
2024-01-26 Delete Filamentalist/Filament Drive Buffer V4 v66.step
    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
2024-01-26 Add files via upload
    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
2024-01-27 Add files via upload
    Add specific CAD directory and loaded updated CAD files that reflect the addition of one screw-on Rim Roller/Hub to provide access for O-Ring replacement.
2024-01-28 Add files via upload
    Slight tweaks:
    Recessed BHCS's on Tensioner arm 1mm and shortened to 16mm
    Lengthened tension screw to 45mm
    Reduced thread count on threaded rim roller to make assembly easier
    Reduced ECAS hole diameter by 0.1mm for more positive press fit
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2024-01-28 Add files via upload
    Updated for the 2020 Clip-In base option
    [Rear Roller Axle.stl]
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2024-01-29 Add files via upload
    Including STL's for CAD ver. 71
    [Axle Pressing Tool.stl, Center Drive Roller Spacer.stl, ECAS Clip.stl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]
2024-01-30 V71 Clip Mount Base Files
    Provide stl's for the 2020 Clip Mount version
    [Left Support Clip Mount.stl, Right Support Clip Mount.stl]
2024-01-30 Add files via upload
    A tiny tweak...Removed chamfers from spacer to provide more build plate adhesion surface are to eliminate the need for brims while printing.
    [Center Drive Roller Spacer.stl]
2024-02-01 V85
    Easy-load funnel Tensioner Mnt. Splined Rim Roller and Hub. Revised Axle Pressing tool for changes in Rim Roller.
    [Rim Roller Splined.stl, Tensioner Mnt.stl]
2024-02-01 V85
    Easy-load funnel version with better alignment to filament path.
    [Tensioner Mnt.stl]
2024-02-01 V85
    Corrected 608 bearing bosses to eliminate center race interference.
    [Left Support.stl, Right Support.stl]
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2024-02-01 Delete Filamentalist/CAD/Filament Driven Buffer v71.step
    replaced by v88
2024-02-01 v89
    Changes:
    1. Replaced threaded Rim Roller with splined version for ease of assembly and removal.
    2. Replaced c-sunk holes on Tensioner Arm with FH.
    3. Revised Tensioner mount for better ECAS alignment and "easy-load" filament funnel.
    4. Reversed the 608 bearing clearance bosses on the R/L Supports to allow the center race to spin freely.
    5. Thickened the wall of the rear roller to reduce stress marks from the pressed in 608 bearings.
    6. Removed the chamfers from the Center Drive Roller Spacers to improve build plate adhesion.
2024-02-01 v91
    Increased clearance around ECAS
    [Tensioner Mnt.stl]
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2024-02-01 v93
    1. Increased ECAS hole on Tensioner Mnt from 8.45mm D to 8.5.
    2. Added clearance for shaft on the end bearing bosses of the Rim Rollers to prevent mushrooming when pressing in shaft.
    3. Increased Rear Roller wall thickness to 2.8mm to reduce stress crazing for bearing press-in.
2024-02-01 v93
    revised clearance for the 608 bearing inner race
    [Left Support Clip Mount.stl, Right Support Clip Mount.stl]
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2024-02-18 v21 (rear wheel drive)
    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
    [Axle Pressing Tool v21.stl, Center Drive Roller Spacer v21.stl, Center Drive Roller v21.stl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]
2024-02-18 Delete Filamentalist/STL's/Left Support v21.stl
    Replaced with a light cosmetic tweak.
    [Left Support v21.stl]
2024-02-18 Delete Filamentalist/STL's/Right Support v21.stl
    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
    [Right Support v21.stl]
2024-02-18 Delete Filamentalist/STL's/Tensioner Mnt v21.stl
    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
    [Tensioner Mnt v21.stl]
2024-02-18 v21 (Rear Wheel Drive)
    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
    [Left Support v21.stl, Right Support v21.stl, Tensioner Mnt v21.stl]
2024-02-18 Delete Filamentalist/CAD/Filament Driven Buffer RWD v21.f3d
    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
    [Filament Driven Buffer RWD v21.f3d]
2024-02-18 Delete Filamentalist/CAD/Filament Driven Buffer RWD v21.step
    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
2024-02-18 v21 (Rear Wheel Drive)
    Updated with a light cosmetic tweak on Supports and Tensioner Mnt
    [Filament Driven Buffer RWD v21.f3d]
2024-02-18 Delete Filamentalist/STL's/Left Support v21.stl
    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
    [Left Support v21.stl]
2024-02-18 v21 (Rear Wheel Drive)
    Updated with a light cosmetic tweak.
    [Left Support v21.stl, Right Support v21.stl]
2024-02-18 v21 (Rear Wheel Drive)
    Updated for a slight cosmetic tweak.
    [Left Support (Clip Mount) v21.stl, Right Support (Clip Mount) v21.stl]
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2024-02-23 RWD v60
    Standardized on a single U-shaped Tensioner Arm. Slight quality of life adjustments to Tensioner Arms and Tensioner Mount (reprint not required for built buffers).
    [Filament Driven Buffer RWD v60.f3d]
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2024-02-26 RWD v60.1
    QoL improvements:
    1. Increased corner radii on triangular press-in peg of tensioner arm
    2. Moved screw position back on "nose" of tensioner are to provide more meat where screw head seats
    No need to replace already printed/built parts
    [Tensioner Arm Left.stl, Tensioner Arm Right.stl]
2024-02-26 Rename Tensioner Arm Left.stl to Tensioner Arm Left (RWD v60.1).stl
    [Tensioner Arm Left (RWD v60.1).stl]
2024-02-26 Delete Filamentalist/STL's/Tensioner Arm Left (RWD v60).stl
    Added small QoL tweaks in v60.1
    [Tensioner Arm Left (RWD v60).stl]
2024-02-26 Rename Tensioner Arm Right.stl to Tensioner Arm Right (RWD v60.1).stl
    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
    [Tensioner Arm Right (RWD v60.1).stl]
2024-02-26 Delete Filamentalist/STL's/Tensioner Arm Right (RWD v60).stl
    replaced with v60.1
    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
    [Tensioner Arm Right (RWD v60).stl]
2024-02-26 RWD V60.1
    These changes do not require reprinting of existing parts.
    Cleaned up artifact that was discovered in the .stp for the Left/Right Support components.
    Reduced contact area of triangular peg on Tensioner Arm Right
    Shifted FHCS hole back on Tensioner Arm Left at "nose" of part to reduce plastic break-out when tightening screw.
    [Filament Driven Buffer RWD v60.1.f3d, Filament Driven Buffer RWD v60.f3d]
2024-02-26 RWD v60.1
    Cleaned up artifact that was discovered in the STEP file for the Left/Right Support components.
    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
    [Left Support (RWD v60).stl, Left Support(RWD v60.1).stl, Right Support (RWD v60).stl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]
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2024-02-29 v6
    added clearance to 1mm spacers
    added chamfers to mag drive disc for printability
2024-03-08 Production Release! v1
    stl, f3d, and stp files released for the formal"production" version of the Filamentalist filament driven buffer
    [Axle Pressing Tool (RWD v60).stl, Axle Pressing Tool v1.stl, Center Drive Roller (RWD v60).stl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]
2024-03-10 Production Release v1!
    Added a standalone flat base for those who want it.
    [Base v1.stl, Base.stl]
2024-03-12 Add files via upload
    This is a Blobifier macro that allows a sw only Blobifier multimaterial purge method.
    [SW Only Blobifier.cfg]
2024-03-15 Add files via upload
    Including blob collection trays and articulated arm for tilting collection tray linked to Z-axis.
    [Arm Lower.stl, Arm Mount.stl, Arm Upper.stl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]
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2024-04-21 V2.1
    Added material around ECAS on Tensioner Mnt to reduce potential for cracking
    Revised Tensioner ARM Left/Right to create clearance for wider Tesnioner Mnt
    Added Test Block V2.1 to check printing tolerances for 608 Bearing, 8mm Axle, and ECAS press fits as well as holes for 3mm screw thread cutting and 2.3mm filament hole.
    [Left Support (2020 Clip-In) V2.stl, Left Support (no-608_2020 Clip-In) v1.stl, Right Support (2020 Clip-In) V2.stl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]
2024-04-21 Replaced Missing Clip-In Folders/Files
    [Left Support (2020 Clip-In) V2.stl, Right Support (2020 Clip-In) V2.stl]
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2024-04-23 Delete Filamentalist/STL's/Tensioner Arm Right V2.1.stl
    Added a V2.1.1 part with built-in support for the locking tab.
    [Tensioner Arm Right V2.1.stl]
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
